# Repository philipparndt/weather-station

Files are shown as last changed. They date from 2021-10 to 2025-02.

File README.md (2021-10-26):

# weather-station

Weather station implemented with esphome

- [ESP32-POE](https://www.olimex.com/Products/IoT/ESP32/ESP32-POE/open-source-hardware)
- [Eltako-Windsensor-WS](https://www.amazon.de/Eltako-Windsensor-WS/dp/B0018LBFG8)
- [Temparature sensors (1-wire)](https://www.amazon.de/gp/product/B075FV3PQR)
- [DHT sensor (humidity / temperature)](https://www.amazon.de/ICQUANZX-AAM2302B-Interface-Temperature-DC3-3-5-5V/dp/B07VBVC366)
- [BH1750 Light sensor](https://www.amazon.de/dp/B07YDH737W)
- [OLED display](https://www.amazon.de/gp/product/B01MSPCZWZ)

Features:
- POE power supply
- Ethernet
- Custom MQTT messages
- Packed in a [electrical junction box](https://www.amazon.de/Kopp-347114008-Abzweigdose-Aufputz-Feuchtraum-Klemmleiste/dp/B00BGT6MK6)

# Messages

// TBD

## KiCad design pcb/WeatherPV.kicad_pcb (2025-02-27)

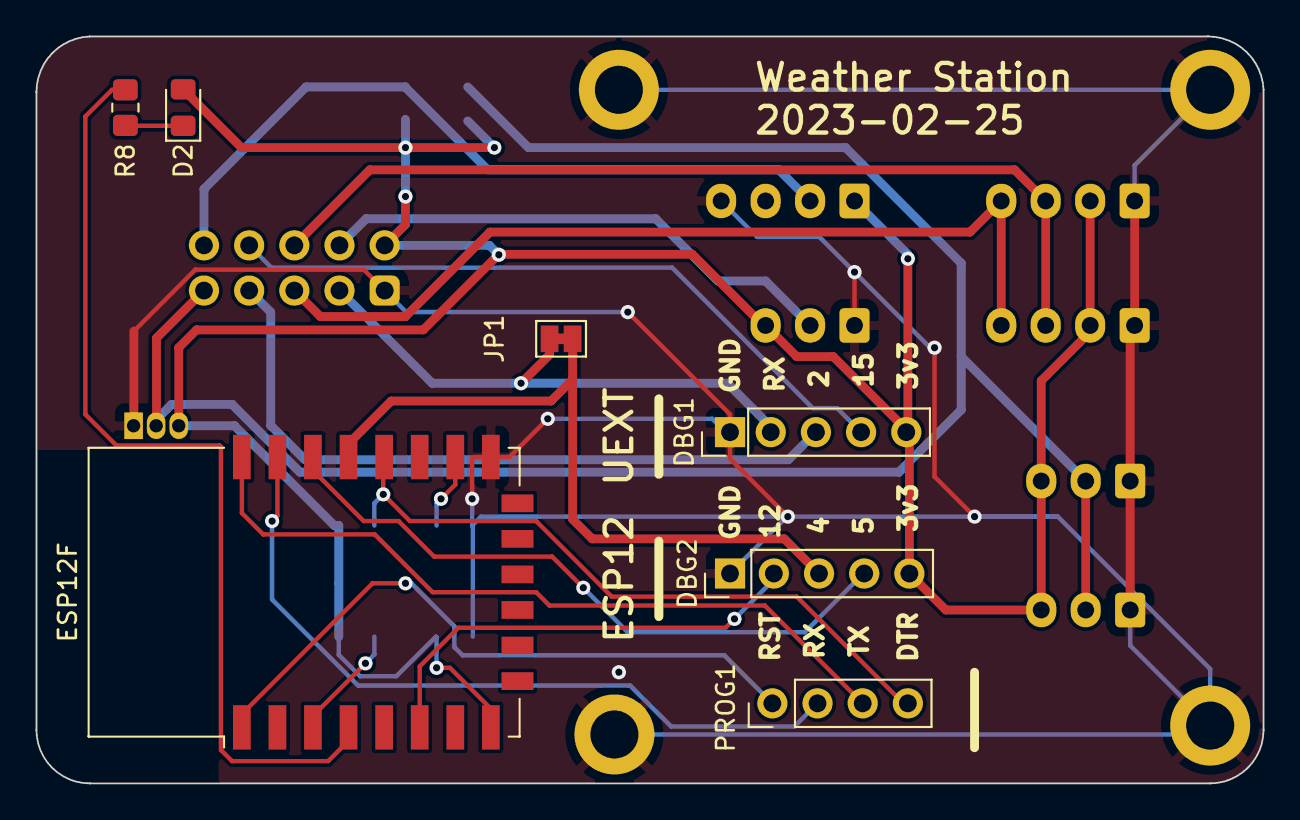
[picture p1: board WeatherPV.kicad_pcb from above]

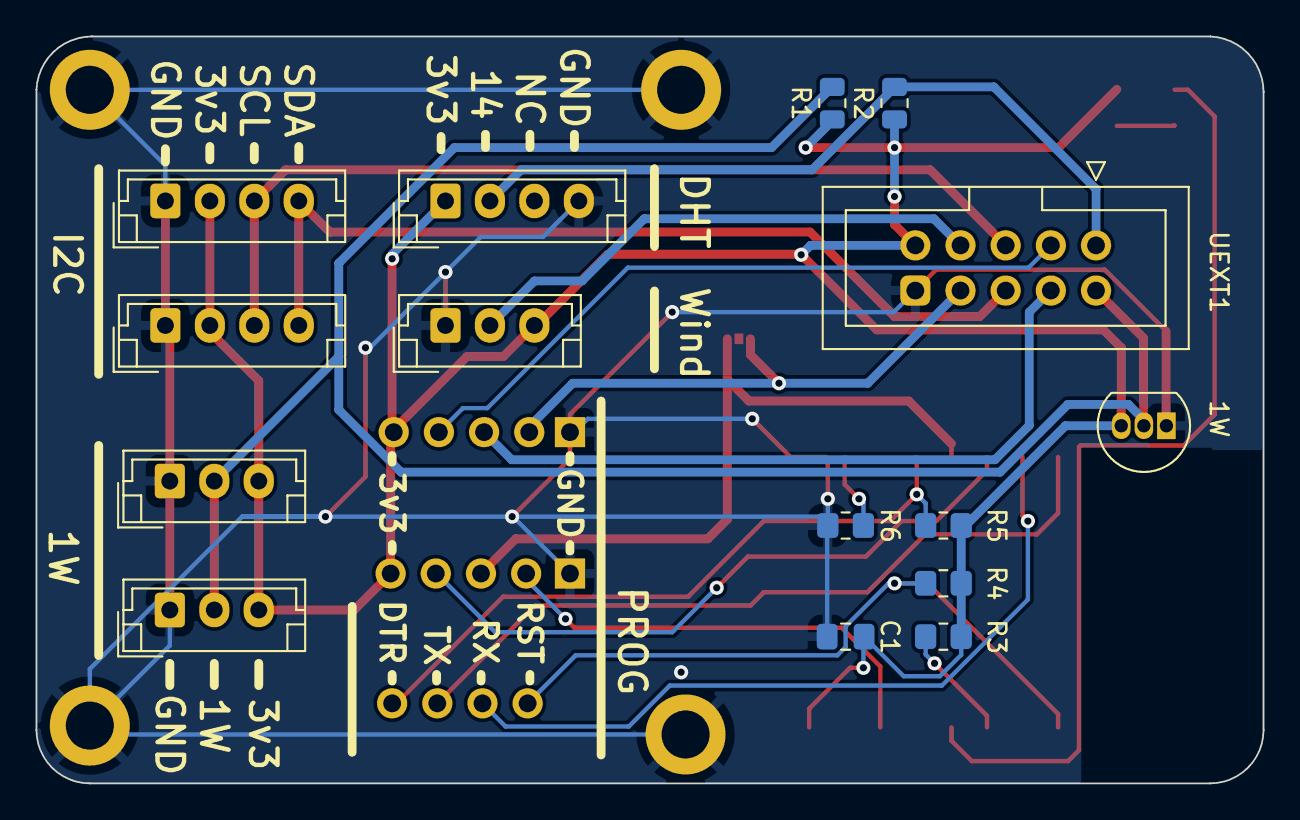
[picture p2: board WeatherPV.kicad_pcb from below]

Board: 2 copper layers, 69.0 x 42.0 mm, 26 parts (15 on the bottom side), 21 nets.

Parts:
1W: DS18B20; TO-92_Inline
1W1, 1W2: 1Wire; JST_EH_B3B-EH-A_1x03_P2.50mm_Vertical
C1: 100n; C_0805_2012Metric_Pad1.18x1.45mm_HandSolder
D2: LED; LED_0805_2012Metric_Pad1.15x1.40mm_HandSolder
DBG1: UEXT_DBG; PinHeader_1x05_P2.54mm_Vertical
DBG2: ESP12_DBG; PinHeader_1x05_P2.54mm_Vertical
DHT22: DHT22; JST_EH_B4B-EH-A_1x04_P2.50mm_Vertical
ESP12F: ESP-12F; ESP-12E
H5, H6, H7, H8: MountingHole_Pad; MountingHole_2.7mm_M2.5_ISO14580_Pad
I2C1, I2C2: I2C; JST_EH_B4B-EH-A_1x04_P2.50mm_Vertical
JP1: Jumper_2_Bridged; SolderJumper-2_P1.3mm_Bridged_Pad1.0x1.5mm
PROG1: ESP12_PROG; PinHeader_1x04_P2.54mm_Vertical
R1: 4k7; R_0805_2012Metric
R2: 10k; R_0805_2012Metric
R3, R4, R5, R6: 10k; R_0805_2012Metric_Pad1.20x1.40mm_HandSolder
R8: 470; R_0805_2012Metric_Pad1.20x1.40mm_HandSolder
UEXT1: UEXT_Host; IDC-Stecker_2x05_P2.54mm_Vertical
Wind1: Wind; JST_EH_B3B-EH-A_1x03_P2.50mm_Vertical

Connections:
1W: 1W.2 (DQ), 1W1.2, 1W2.2, R1.2, UEXT1.10 (~SSEL)
+3V3: 1W.3 (VDD), 1W1.3, 1W2.3, C1.1, D2.2 (A), DBG1.5, DBG2.5, DHT22.1 (VCC), ESP12F.8 (VCC), I2C1.2, I2C2.2, R1.1, R2.1, R3.1, R4.1, R5.2, UEXT1.1 (3V3), Wind1.3
ESP12_DTR: ESP12F.18 (GPIO0), PROG1.4, R5.1
ESP12_GPIO5: DBG2.4, ESP12F.20 (GPIO5)
ESP12_GPIO12: DBG2.2, ESP12F.6 (GPIO12)
ESP12_RESET: ESP12F.1 (~RST), PROG1.1, R4.2
ESP12_RX: ESP12F.21 (GPIO3/RXD), PROG1.2
ESP12_TX: ESP12F.22 (GPIO1/TXD), PROG1.3
GND: 1W.1 (GND), 1W1.1, 1W2.1, C1.2, DBG1.1, DBG2.1, DHT22.4 (GND), ESP12F.15 (GND), H5.1, H6.1, H7.1, H8.1, I2C1.1, I2C2.1, R6.2, UEXT1.2 (GND), Wind1.1
GPIO2: DBG1.3, UEXT1.8 (MOSI)
GPIO4: UEXT1.3 (TXD), Wind1.2
GPIO14: DHT22.2 (IO), R2.2, UEXT1.9 (SCK)
GPIO15: DBG1.4, UEXT1.7 (MISO)
unnamed: D2.1 (K), R8.1
unnamed: ESP12F.3 (EN), R3.2
unnamed: ESP12F.16 (GPIO15), R6.1
unnamed: ESP12F.4 (GPIO16), R8.2
RXD: DBG1.2, JP1.1 (A), UEXT1.4 (RXD)
SCL: I2C1.3, I2C2.3, UEXT1.5 (SCL)
SDA: I2C1.4, I2C2.4, UEXT1.6 (SDA)
UART_CONNECT: DBG2.3, ESP12F.19 (GPIO4), JP1.2 (B)

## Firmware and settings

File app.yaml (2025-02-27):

substitutions:
  temperature_update_time: 5s
  publish_energy_interval: 5s
  publish_wind_interval: 5s
  publish_temperature_interval: 60s
  device_name: "weather-station-esp32"
  appversion: "1.0.0"
  base_topic: "garden/weather"
  base_topic_prod: "garden/weather"

esphome:
  name: ${device_name}
  platform: ESP32
  board: esp32-poe-iso
  includes:
    - eth/eth-address.h
    - deye_uart_read_line_sensor.h

globals:
  - id: current_screen
    type: int
    restore_value: no
    initial_value: '0'

external_components:
  - source: github://uriyacovy/ESPHome_nuki_lock
  - source: github://mill1000/esphome-status-text-sensor

packages:
  mqtt:     !include config/mqtt.yaml
  ethernet: !include config/ethernet.yaml
  i2c:      !include config/i2c.yaml
#  font:     !include ui/fonts/fonts.yaml
#  display:  !include ui/display.yaml

# Enable logging
logger:
  level: INFO
  #level: DEBUG
  #level: VERBOSE

# Enable Home Assistant API
api:
  password: "1234"

ota:
  platform: "esphome"
  password: "1234"

web_server:
  port: 80

uart:
  id: uart_bus
#  tx_pin: D0
  rx_pin: GPIO36
  baud_rate: 9600
  data_bits: 8
  parity: NONE
  stop_bits: 1

# Example configuration entry
one_wire:
  platform: gpio
  pin: GPIO5

# Individual sensors
sensor:
  - <<: !include sensors/wind.yaml
  - <<: !include sensors/internal.yaml
  - <<: !include sensors/indoor.yaml
  - <<: !include sensors/outdoor.yaml
  - <<: !include sensors/illuminance.yaml
  - <<: !include sensors/dht.yaml

  - <<: !include mqtt/json/wind.yaml
  - <<: !include mqtt/json/internal.yaml
  - <<: !include mqtt/json/indoor.yaml
  - <<: !include mqtt/json/outdoor.yaml
  - <<: !include mqtt/json/illuminance.yaml
  - <<: !include mqtt/json/dht.yaml
  - <<: !include mqtt/json/energy.yaml

  - platform: uptime
    name: "Device Uptime"
    id: device_uptime
    update_interval: 2s  # Check every 5 seconds
    internal: true

# Nuki
#<<: !include nuki/nuki.yaml
#<<: !include nuki/unifi_button.yaml


#  - <<: !include ui/screen-toggle.yaml

text_sensor:
  # Version Text Sensor
  # see: https://esphome.io/components/text_sensor/version.html?highlight=platform%20version
  - platform: version
    name: ${device_name} Version
    id: appver
    internal: true

  - platform: custom
    lambda: |-
      auto my_custom_sensor = new DeyeUartReadLineSensor(id(uart_bus));
      App.register_component(my_custom_sensor);
      return {my_custom_sensor};
    text_sensors:
      id: "energy_sensor"

  - platform: status
    name: Status

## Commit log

2021-08-29 round temperatures
2021-10-25 update dht sensor
2023-04-06 filter invalid values
2025-02-27 chore(deps) (#1)
    [WeatherPV.kicad_pcb, WeatherPV.kicad_sch]
